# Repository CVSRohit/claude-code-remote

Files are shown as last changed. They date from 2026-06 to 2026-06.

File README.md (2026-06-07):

# Claude Code Remote

A physical remote control for [Claude Code](https://www.claude.com/product/claude-code).
An ESP32 with a 1.3" screen and **four buttons** lets you **launch prompts**,
**approve or deny every tool call with a button**, **scroll Claude's output**, and
**interrupt a run** — from anywhere, while Claude runs on your own PC against your
own files.

```
┌─────────────────────────┐   wss/TLS   ┌──────────────┐   wss (outbound)   ┌────────────────────────────┐
│ ESP32                   │ ──────────▶ │  Fly.io relay │ ◀───────────────── │  runner (Node, your PC)    │
│ ST7789 240x240          │             │  token-paired │                    │   → Claude Agent SDK       │
│ 4 buttons  ▲ ▼ ✓ ✗     │ ◀────────── │   WS hub      │ ─────────────────▶ │   → Claude Code + your fs  │
└─────────────────────────┘             └──────────────┘                    └────────────────────────────┘
        approve / deny / launch / interrupt              status / tool / text / result
```

Claude Code can't run on an ESP32 (it needs Node + a filesystem), so the ESP32 is
a thin client. This mirrors Claude Code's own **Remote Control** model — the
machine that owns the files dials *outbound* to a relay, nothing inbound — except
here the runner uses the **Agent SDK**, whose `canUseTool` callback gives you the
physical **approve/deny** that the official remote control can't do.

Three components, one per folder:

| Folder | Runs on | What it is |
|---|---|---|
| `relay/` | Fly.io (or any host) | A tiny stateless WebSocket hub. Pairs one device to one runner by a shared token and forwards JSON. Holds no API key, no files. |
| `bridge/` | Your PC | The "runner". Dials out to the relay, drives Claude Code via the Agent SDK against your local files. |
| `firmware/` | ESP32 | The handheld remote (PlatformIO). |

## 🛠 Build one yourself

Full parts list, wiring, 3D-printed case, and step-by-step assembly are in
**[docs/BUILD.md](docs/BUILD.md)**. Printable STLs (base, lid, fit-test) and the
parametric source live in **[hardware/case](hardware/case)**.

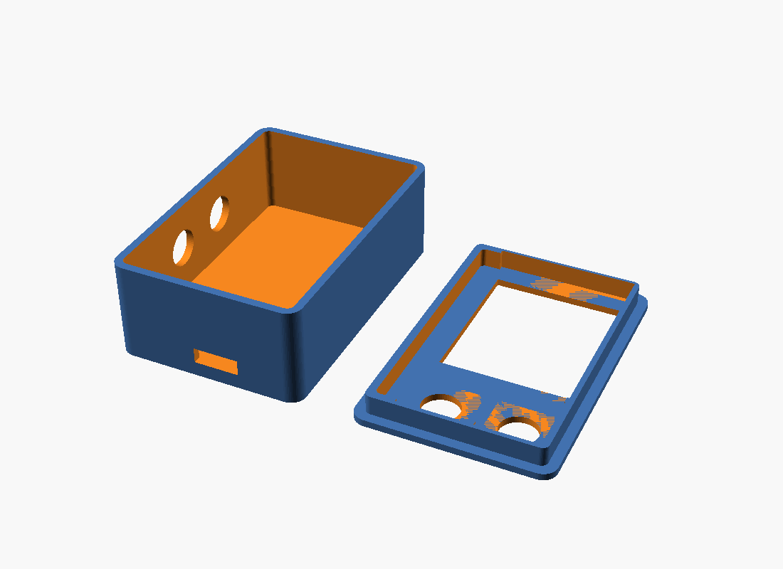
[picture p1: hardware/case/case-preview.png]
case preview


## Two modes (toggle on-device — top menu row, press ✓)

- **ask**  — the SDK `canUseTool` callback *blocks* on each tool call; the screen
  shows the command and waits: **✓ = allow, ✗ = deny**.
- **auto** — `permissionMode: bypassPermissions` runs unattended, but a
  `PreToolUse` hook still streams every tool call to the screen so you *see* every
  action. Hit **✗ while running to interrupt**.

---

## Setup

A shared **token** ties all three pieces together. Generate one:

```bash
node -e "console.log(require('crypto').randomBytes(18).toString('base64url'))"
```

### 1. Relay (Fly.io)

```bash
cd relay
fly apps create your-relay-name
fly secrets set RELAY_TOKEN=<token> --app your-relay-name --stage
fly deploy --app your-relay-name --ha=false   # edit app name in fly.toml first
```

Your relay is now at `wss://your-relay-name.fly.dev/`.

### 2. Runner (your PC)

Requires Node 18+ and Claude Code authenticated on this machine (the Agent SDK
reuses your existing Claude Code auth).

```bash
cd bridge
npm install
cp .env.example .env        # set RELAY_URL=wss://your-relay-name.fly.dev/ and RELAY_TOKEN=<token>
npm start
```

Edit `presets.json` to change the menu and which folder Claude operates in
(`defaultCwd`, or per-preset `cwd`).

### 3. Firmware (ESP32)

```bash
cd firmware
cp include/secrets.h.example include/secrets.h   # set WiFi (2.4GHz), RELAY_HOST, RELAY_TOKEN
pio run -t upload
pio device monitor
```

---

## Wiring (ESP32 devkit → ST7789 240×240)

| ST7789 | ESP32 | | Button | ESP32 |
|---|---|-|---|---|
| VCC | 3V3 | | ▲ UP | GPIO25 → GND |
| GND | GND | | ▼ DOWN | GPIO26 → GND |
| SCL/SCLK | GPIO18 | | ✓ OK (green) | GPIO27 → GND |
| SDA/MOSI | GPIO23 | | ✗ BACK (red) | GPIO33 → GND |
| RES/RST | GPIO4 | | | |
| DC | GPIO2 | | | |
| BLK | GPIO32 | | | |

- **No CS pin** — these 7-pin boards have CS tied active internally; `platformio.ini`
  sets `TFT_CS=-1`. Leave it unconnected.
- **VCC = 3.3V, not 5V** (the panel logic is 3.3V; no onboard regulator).
- **BLK → GPIO32** so firmware controls the backlight: it sleeps after 60s idle
  and wakes on any button or an incoming approval. Prefer always-on? Wire BLK to
  3V3 instead (the screen just won't sleep).
- Buttons are bare tactile switches, one leg to the GPIO and one to GND — internal
  pull-ups, no resistors.
- SPI is set to 27 MHz in `platformio.ini`; drop it (e.g. 10 MHz) if a long/cheap
  jumper run gives a blank screen.

TFT pins live in `platformio.ini` `build_flags`; button pins at the top of
`firmware/src/main.cpp`.

## Controls

| Screen | ▲ UP | ▼ DOWN | ✓ OK | ✗ BACK |
|---|---|---|---|---|
| Menu | prev row | next row | activate row¹ | — |
| Approval | scroll cmd ↑ | scroll cmd ↓ | **ALLOW** | **DENY** |
| Running  | scroll log ↑ | scroll log ↓ | — | **interrupt run** |
| Result | scroll ↑ | scroll ↓ | back to menu | back to menu |

¹ The menu's top row is `Mode: ask/auto` — ✓ toggles the mode; ✓ on any other row
launches that preset.

## Security

The relay is reachable on the public internet, so it's **token-gated**: a client
must present the shared `RELAY_TOKEN` to be paired into a room. Keep it secret —
it (and your WiFi password) live in gitignored files (`bridge/.env`,
`firmware/include/secrets.h`); `.example` templates are committed. In `auto` mode
the runner uses `bypassPermissions`, so treat the token like a key to your shell.

## 3D-printed enclosure

A two-part handheld case (base + lid) is in [`hardware/case`](hardware/case) —
printable STLs plus a parametric OpenSCAD source you can tweak to your exact
boards. **Print `fit-test.stl` first** to check the screen/button fit. See the
[build guide](docs/BUILD.md#3-print-the-case) for print settings and assembly.

## Notes & extensions

- Single device + single runner per token; newest connection of each role wins.
- Output is buffered on-device into a scrollable log; ▲/▼ scroll, the running log
  auto-follows the newest line until you scroll up.
- Interrupt: ✗ while running sends `{type:"interrupt"}`; the runner aborts the run.
- Want free-form prompts without a keyboard? The ESP32 pairs well with an INMP441
  mic — capture audio, send to the runner, transcribe, feed as a prompt.

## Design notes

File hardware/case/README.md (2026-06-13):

# Enclosure — 3D printed case

A custom two-part handheld case for the Claude Code Remote, sized to an ESP32
(52×28, USB-C) with a 1.3" ST7789 bolted on top (~17 mm stack). **~39 × 58 × 21 mm.**

| File | Print | Notes |
|---|---|---|
| `base.stl` | 1× | Tray for the ESP32+screen stack. USB-C cutout on the bottom end; 2 cap holes on the left wall for the scroll buttons. |
| `lid.stl` | 1× | Front plate: screen window + the 2 action-button cap holes below it. Print **face-down**. |
| `claude-code-remote-case.scad` | — | Parametric source — every dimension is at the top. |

preview

## Layout

- **Screen** centered up top behind the lid window (1.4 mm bezel).
- **Action buttons (✓ ✗)** — two 7.6 mm cap holes on the lid, below the screen.
- **Scroll buttons (▲ ▼)** — two 7.6 mm cap holes on the **left wall**; the
  12×12×3 mm switches stand on edge in the left channel, caps facing out.
- No screws — **base and lid glue/tape together**; the side switches glue into
  the channel.

## Print settings

PLA or PETG · 0.2 mm layers · 4 perimeters (walls are 1.6 mm) · 20% infill ·
**no supports** (print the lid face-down).

## Customizing

Open `claude-code-remote-case.scad`, edit the `CONFIG` block (board size, stack
height, screen window, button positions, channel width, wall thickness), then:

```bash
openscad -o base.stl -D pn=1 claude-code-remote-case.scad
openscad -o lid.stl  -D pn=2 claude-code-remote-case.scad
```

See [`../../docs/BUILD.md`](../../docs/BUILD.md) for the full build.

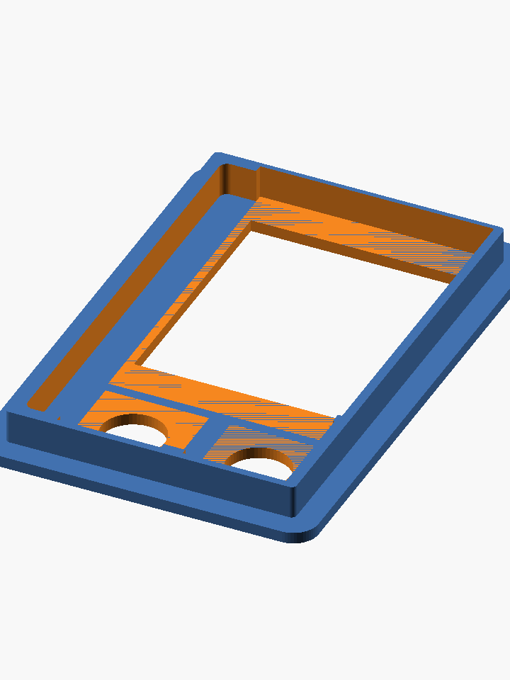
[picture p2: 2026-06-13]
hardware/case/lid-front.png

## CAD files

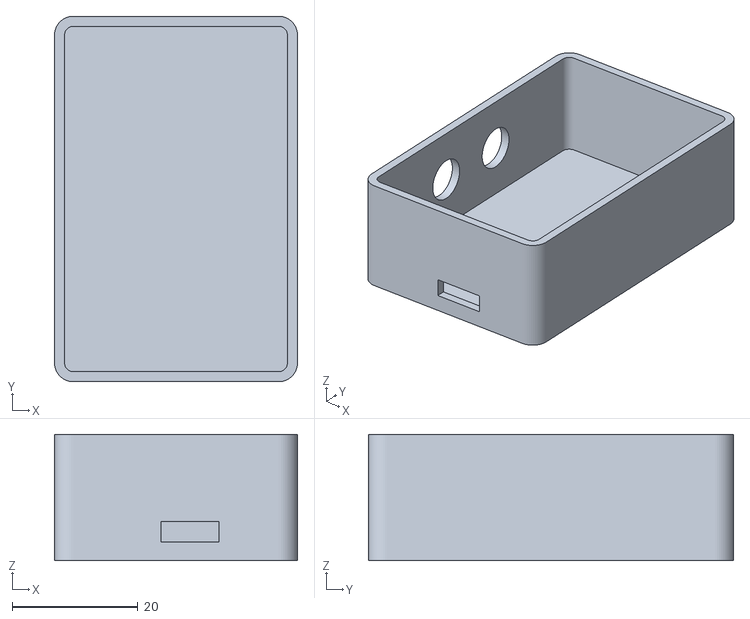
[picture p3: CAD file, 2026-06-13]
hardware/case/base.stl
38.7 x 58.2 x 20.1

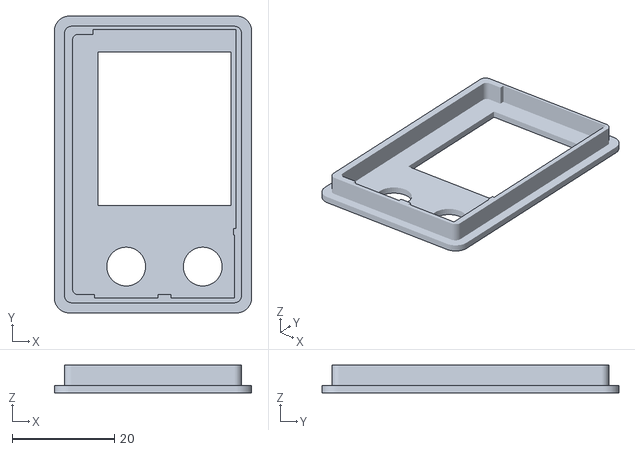
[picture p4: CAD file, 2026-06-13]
hardware/case/lid.stl
38.7 x 58.2 x 5.40

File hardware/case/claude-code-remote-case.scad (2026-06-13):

/* ============================================================
   Claude Code Remote — custom handheld case (v3)

   Layout:
     - ESP32 (52x28, USB-C) + ST7789 stacked on the RIGHT side of the case.
     - A LEFT CHANNEL runs alongside the boards; the two SCROLL buttons (▲ ▼)
       stand vertically in it, caps facing OUT the left wall (perpendicular to
       the boards), bodies wedged against the boards' left edges.
     - Screen window at the TOP (over the boards); two ACTION buttons (✓ ✗)
       on the face just below the screen.
     - 2 screws in the left channel (top + bottom), clear of the side buttons.

   Render:
     openscad -o base.stl -D pn=1 claude-code-remote-case.scad
     openscad -o lid.stl  -D pn=2 claude-code-remote-case.scad
   ============================================================ */

part = "both";
pn = -1;  // CLI: 0 both, 1 base, 2 lid

/* ---------------- CONFIG (measure & adjust) ---------------- */
// ESP32
esp_l   = 52;
esp_w   = 28;
esp_h   = 13;     // ESP32 height incl. soldered pins
stack_h = 17;     // ESP32 + ST bolted together (measured)
usb_w   = 9.2;
usb_h   = 3.2;
usb_cz  = 3.0;    // USB-C centre height above floor — CONFIRM

// Screen (ST7789)
scr_pcb_w = 28;
scr_pcb_l = 39;
scr_pcb_t = 1.8;
scr_win_w = 26;   // +1mm wider
scr_win_h = 30;
scr_cy    = 7;    // screen centre toward the TOP
scr_gap   = 6;    // gap ESP32 top -> screen — CONFIRM

// Buttons: 12x12x5 DIP tactile, 7mm round cap
btn       = 12.4; // square body footprint
btn_hole  = 7.6;  // round cap hole
btn_depth = 3;    // switch body depth into the channel
fbtn_y    = -20;  // action buttons centre line, clear of the ST PCB above
fbtn_dx   = 7.5;  // their left/right spacing
sbtn_y1   = 7;    // scroll ▲ (left channel, toward top)
sbtn_y2   = -7;   // scroll ▼ (left channel, toward bottom)

// Case
channel_w  = 6;     // left channel width for the side buttons (3mm switch + room)
right_clear = 1.5;  // clearance on the board (right) side
wall   = 1.6;   // base wall thickness (4 perimeters @ 0.4 nozzle)
gap    = 0.4;
fillet = 3;
lip_h  = 4;
lip_wall = 1.6;
screw_pilot = 1.7;
screw_clear = 2.4;
screw_head  = 4.2;
post_d      = 5.0;
post_inset  = 3.0;

$fn = 56;

/* ---------------- DERIVED ---------------- */
inner_w = esp_w + right_clear + channel_w;          // boards right, channel left
inner_l = esp_l + 3;
inner_d = stack_h + 1.5;                             // fit the bolted ESP32+ST stack
board_cx = inner_w / 2 - right_clear - esp_w / 2;   // board centre, shifted right
sbtn_z  = wall + inner_d / 2;                        // side button centre depth
out_w = inner_w + 2 * wall;
out_l = inner_l + 2 * wall;
base_d = inner_d + wall;
lid_t  = 1.4;   // thin face so 3mm button caps poke through (matches screen bezel)

/* ---------------- HELPERS ---------------- */
module rbox(w, l, h, r) {
  hull() for (x = [-1, 1], y = [-1, 1])
    translate([x * (w / 2 - r), y * (l / 2 - r), 0]) cylinder(h = h, r = r);
}
module post_xy() {  // 2 posts in the LEFT channel (top + bottom)
  for (y = [-1, 1])
    translate([-(inner_w / 2 - post_inset), y * (inner_l / 2 - post_inset), 0]) children();
}

/* ---------------- BASE ---------------- */
module base() {
  difference() {
    rbox(out_w, out_l, base_d, fillet);
    translate([0, 0, wall]) rbox(inner_w, inner_l, base_d, max(0.6, fillet - wall));
    // USB-C on bottom end wall, aligned to the board (shifted right)
    translate([board_cx, -out_l / 2, wall + usb_cz]) cube([usb_w, 3 * wall, usb_h], center = true);
    // scroll buttons: round cap holes through the LEFT (-x) wall only
    for (yy = [sbtn_y1, sbtn_y2])
      translate([-out_w / 2 - 1, yy, sbtn_z]) rotate([0, 90, 0]) cylinder(h = wall + 3, d = btn_hole);
  }
  // (side-button switches glue into the channel; base+lid glue/tape together)
}

/* ---------------- LID ---------------- */
module lid() {
  difference() {
    union() {
      rbox(out_w, out_l, lid_t, fillet);
      translate([0, 0, lid_t - 0.5]) difference() {
        rbox(inner_w - 2 * gap, inner_l - 2 * gap, lip_h + 0.5, max(0.6, fillet - wall));
        translate([0, 0, -1]) rbox(inner_w - 2 * gap - 2 * lip_wall, inner_l - 2 * gap - 2 * lip_wall, lip_h + 2.5, 1);
      }
    }
    // screen PCB recess (bezel ~1.4mm), shifted right over the boards
    translate([board_cx - scr_pcb_w / 2, scr_cy - scr_pcb_l / 2, 1.4])
      cube([scr_pcb_w, scr_pcb_l, lid_t + lip_h + 2]);
    // screen window
    translate([board_cx, scr_cy, -1])
      linear_extrude(lid_t + lip_h + 2) square([scr_win_w, scr_win_h], center = true);
    // action buttons below the screen (cap holes + 12x12 body wells)
    for (x = [-1, 1]) {
      translate([board_cx + x * fbtn_dx, fbtn_y, -1]) cylinder(h = lid_t + 2, d = btn_hole);
      translate([board_cx + x * fbtn_dx, fbtn_y, lid_t]) linear_extrude(lip_h + 1) square([btn, btn], center = true);
    }
  }
}

/* ---------------- RENDER ---------------- */
sel = pn == 0 ? "both" : pn == 1 ? "base" : pn == 2 ? "lid" : part;
if (sel == "base") base();
else if (sel == "lid") lid();
else { base(); translate([out_w + 10, 0, 0]) lid(); }

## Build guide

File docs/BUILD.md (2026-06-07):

# Build your own Claude Code Remote

This guide takes you from parts to a working handheld remote. For how the system
works end-to-end, see the [main README](../README.md).

Rough time: **1–2 hours** (plus print time). Skill level: beginner-friendly
soldering (4 buttons) + flashing a dev board.

---

## 1. Bill of materials

| # | Part | Qty | ~Cost | Notes |
|---|---|-----|---|---|
| 1 | **ESP32 dev board** (DevKitC / WROOM-32, 38-pin) | 1 | $5–8 | Any ESP32 with a USB-serial chip (CP2102/CH340). |
| 2 | **1.3" ST7789 IPS display**, 240×240, SPI, **7-pin (no CS)** | 1 | $5–7 | Pin order `GND VCC SCL SDA RES DC BLK`. 3.3V board. |
| 3 | **6×6 mm tactile push buttons** | 4 | ~$1 | Through-hole, ~5 mm plunger. |
| 4 | **Jumper wires** (female–female) | ~12 | ~$2 | To connect display + buttons to the header pins. |
| 5 | **M2 × 6 mm self-tapping screws** | 2 | ~$1 | Hold the lid to the base. |
| 6 | **USB data cable** | 1 | — | Match your board (micro-USB or USB-C). **Data**, not charge-only. |
| 7 | **3D-printed case** (base + lid) | 1 set | filament | See [`hardware/case`](../hardware/case). |
| 8 | Foam pad / double-sided tape | a little | — | Optional: pad the ESP32 in the tray, hold the screen. |

You also need a **2.4 GHz WiFi** network (ESP32 has no 5 GHz) and a PC that runs
Claude Code, plus a [Fly.io](https://fly.io) account (free tier is fine) for the
relay.

### Tools
- Soldering iron + solder (to attach wires to the 4 buttons)
- 3D printer (or a print service)
- Small Phillips screwdriver
- A computer with [PlatformIO](https://platformio.org) and [Node 18+](https://nodejs.org)

---

## 2. Wiring

All display power is **3.3V** (not 5V). All grounds are common.

### Display (ST7789) → ESP32

| ST7789 | ESP32 |
|---|---|
| VCC | 3V3 |
| GND | GND |
| SCL | GPIO18 |
| SDA | GPIO23 |
| RES | GPIO4 |
| DC  | GPIO2 |
| BLK | GPIO32 |

> No CS pin — the firmware sets `TFT_CS=-1`. Leave it unconnected.
> BLK is on GPIO32 (not 3V3) so the firmware can sleep the backlight after 60s
> idle and wake on a button/approval. Wire BLK to 3V3 instead if you want it
> always on.

### Buttons → ESP32

Each button: one leg to its GPIO, the other leg to **GND** (all four GND legs can
share one ground wire). Internal pull-ups are enabled, so no resistors.

| Button | ESP32 |
|---|---|
| ▲ UP | GPIO25 |
| ▼ DOWN | GPIO26 |
| ✓ OK (green) | GPIO27 |
| ✗ BACK (red) | GPIO33 |

---

## 3. Print the case

In [`hardware/case`](../hardware/case):

1. **Print `fit-test.stl` first** and check your screen + buttons drop into it.
   Adjust the `CONFIG` block in the `.scad` and re-render if anything is off.
2. Print `base.stl` and `lid.stl` (print the lid **front-face-down**).

Print settings: PLA/PETG, 0.2 mm layers, 3 walls, 20% infill, no supports.

case preview

---

## 4. Assemble

1. **Buttons:** solder a wire to each button (signal + ground). Press the four
   buttons into the wells on the inside of the lid (▲▼ left column, ✓✗ right).
2. **Screen:** seat the display into the recess behind the lid window, active area
   facing out. Hold it with a dab of hot glue or tape on the PCB edges.
3. **Wire it up** per section 2 — display and buttons to the ESP32 header.
4. **ESP32:** place it in the base with the USB port lined up to the cutout. Pad
   with foam/tape so it doesn't rattle.
5. Close the lid onto the base and fasten the **2 M2 screws** at the bottom.

---

## 5. Flash the firmware

```bash
cd firmware
cp include/secrets.h.example include/secrets.h
# edit secrets.h: WIFI_SSID/PASS (2.4GHz), RELAY_HOST, RELAY_TOKEN
pio run -t upload
pio device monitor          # watch it boot, join WiFi, connect to the relay
```

You generate `RELAY_TOKEN` and deploy the relay in the next step — come back and
fill it in.

---

## 6. Software: relay + runner

Do this once. Full detail is in the [README](../README.md#setup); the short version:

```bash
# pick a shared secret used by the relay, runner, and firmware
node -e "console.log(require('crypto').randomBytes(18).toString('base64url'))"

# relay (Fly.io) — edit the app name in relay/fly.toml first
cd relay
fly apps create your-relay-name
fly secrets set RELAY_TOKEN=<token> --app your-relay-name --stage
fly deploy --app your-relay-name --ha=false

# runner (your PC, where Claude Code is logged in)
cd ../bridge
npm install
cp .env.example .env        # RELAY_URL=wss://your-relay-name.fly.dev/  +  RELAY_TOKEN=<token>
npm start
```

Put the same `RELAY_HOST` (`your-relay-name.fly.dev`) and `RELAY_TOKEN` into
`firmware/include/secrets.h` and re-flash.

---

## 7. First run

1. Runner terminal shows `Paired with relay (device online: true)`.
2. The device screen shows the menu: `MODE: ask` + your presets.
3. Highlight a preset with ▲/▼, press ✓ to launch.
4. In **ask** mode each tool call shows on screen — press ✓ to allow, ✗ to deny.
5. It finishes on a green **DONE** screen with the run cost.

Point the runner at any local folder (or a cloned repo) via `defaultCwd` / per-preset
`cwd` in `bridge/presets.json`.

---

## 8. Troubleshooting

| Symptom | Fix |
|---|-----|
| **Screen lit but blank** | A loose/wrong data wire (DC, RES, SDA, SCL) — re-seat them. If on long jumpers, lower `SPI_FREQUENCY` in `platformio.ini` (try 10 MHz). |
| **Screen totally dark** | No backlight — check BLK→3V3, VCC→3V3, common GND. |
| **Screen garbled / wrong colors** | SPI integrity (shorten/reseat wires, lower SPI freq) or driver flags. |
| **Won't connect to WiFi** | Must be **2.4 GHz**; check SSID/pass in `secrets.h`. |
| **`Waiting for runner`** | The runner isn't connected — start it (`npm start`) and check `RELAY_TOKEN` matches in all three places. |
| **`auth failed` on screen** | Token mismatch between firmware, runner `.env`, and the Fly secret. |
| **Upload "chip stopped responding"** | Hold the **BOOT** button during upload, or unplug/replug and retry. |
| **Buttons do the wrong thing** | Check each button's GPIO matches section 2. |

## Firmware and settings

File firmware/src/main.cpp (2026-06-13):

/**
 * Claude Code remote — ESP32 firmware (4-button edition).
 *
 * Hardware: ESP32 + 1.3" ST7789 240x240 IPS LCD + 4 tactile buttons.
 * Talks JSON over WebSocket to the PC bridge (see ../bridge).
 *
 * Buttons (all active-low to GND, internal pull-ups):
 *   UP (▲)  DOWN (▼)  OK (✓, green)  BACK (✗, red)
 *
 * Each button keeps ONE meaning everywhere:
 *   ▲ / ▼  always move the selection or scroll text
 *   ✓      always the affirmative  (launch / allow / continue)
 *   ✗      always the negative     (deny / back / interrupt)
 *
 * Per-screen behaviour:
 *   MENU     : ▲/▼ move, ✓ activate row (row 0 = toggle ask/auto, rest = launch)
 *   RUNNING  : ▲/▼ scroll log, ✗ interrupt the run
 *   APPROVAL : ▲/▼ scroll command, ✓ ALLOW, ✗ DENY
 *   RESULT   : ▲/▼ scroll output, ✓ or ✗ back to menu
 *
 * See README.md for wiring.
 */

#include <Arduino.h>
#include <WiFi.h>
#include <WebSocketsClient.h>
#include <ArduinoJson.h>
#include <TFT_eSPI.h>

// ---------- USER CONFIG ----------
// Real values live in include/secrets.h (gitignored). The fallbacks below let
// the project compile without it. RELAY_TOKEN must match the runner + Fly secret.
#if defined(__has_include)
#  if __has_include("secrets.h")
#    include "secrets.h"
#  endif
#endif
#ifndef WIFI_SSID
#  define WIFI_SSID "YOUR_WIFI"
#endif
#ifndef WIFI_PASS
#  define WIFI_PASS "YOUR_PASSWORD"
#endif
#ifndef RELAY_HOST
#  define RELAY_HOST "cc-remote-relay-rohit.fly.dev"
#endif
#ifndef RELAY_PORT
#  define RELAY_PORT 443
#endif
#ifndef RELAY_TOKEN
#  define RELAY_TOKEN "PASTE_TOKEN_HERE"
#endif

// ---------- PINS (buttons, active-low) ----------
static const int PIN_UP = 25;   // ▲
static const int PIN_DOWN = 26;  // ▼
static const int PIN_OK = 27;    // ✓ green
static const int PIN_BACK = 33;  // ✗ red
static const int PIN_BL = 32;    // backlight enable (move display BLK here from 3V3)
// TFT pins are set in platformio.ini build flags.

// ---------- GLOBALS ----------
TFT_eSPI tft = TFT_eSPI();
WebSocketsClient ws;

enum UiState { ST_BOOT, ST_SESSIONS, ST_MENU, ST_MONITOR, ST_RUNNING, ST_APPROVAL, ST_RESULT };
UiState state = ST_BOOT;

static const int MAX_PRESETS = 10;
String presetLabels[MAX_PRESETS];
int presetCount = 0;
int selection = 0; // 0 = mode row, 1..presetCount = presets

static const int MAX_SESSIONS = 8;
String sessionNames[MAX_SESSIONS];
String sessionIds[MAX_SESSIONS];
int sessionCount = 0;
int sessionSel = 0;

String currentMode = "ask";
String statusText = "Connecting…";
String toolName = "";
String toolSummary = "";
String pendingToolId = "";
String logBuf = "";   // accumulated tool calls + prose during a run
String resultText = "";
bool resultOk = false;
float resultCost = 0;

int scroll = 0;          // line offset for scrollable views
bool followBottom = true; // auto-stick RUNNING log to the newest line
bool dirty = true;        // redraw flag
bool wsUp = false;        // websocket connected (diagnostics)
bool screenAsleep = false;       // backlight off after idle
uint32_t lastActivity = 0;       // last button / message time
static const uint32_t SLEEP_MS = 60000; // idle timeout before backlight off
void wake();        // forward decls (used in handleMessage, defined near setup)
void sleepScreen();

// ---------- COLORS ----------
#define COL_BG TFT_BLACK
#define COL_ACCENT 0x05D4 // teal
#define COL_DIM 0x7BEF
#define COL_OK 0x07E0
#define COL_BAD 0xF800
#define COL_WARN 0xFD20

// ---------- LAYOUT ----------
#define BODY_Y 30
#define LINE_H 12
static const int CHARS_PER_LINE = 37; // ~224px / 6px (font 1)

// Debounced active-low edge detector.
struct Button {
  int pin;
  bool last = HIGH;
  uint32_t tEdge = 0;
  Button(int p) : pin(p) {}
  bool pressed() {
    bool now = digitalRead(pin);
    if (now != last && (millis() - tEdge) > 40) {
      tEdge = millis();
      last = now;
      if (now == LOW) return true;
    }
    last = now;
    return false;
  }
};
Button btnUp{PIN_UP}, btnDown{PIN_DOWN}, btnOk{PIN_OK}, btnBack{PIN_BACK};

// ---------- TEXT WRAP / SCROLL ----------
static const int MAX_LINES = 90;
String wrapped[MAX_LINES];
int lineCount = 0;

// Word-wrap `s` into the `wrapped` array (honours embedded '\n').
void buildLines(const String &s, int perLine) {
  lineCount = 0;
  int start = 0, lastSpace = -1;
  int len = s.length();
  for (int i = 0; i <= len && lineCount < MAX_LINES; i++) {
    char c = (i < len) ? s[i] : '\n';
    if (c == '\n') {
      wrapped[lineCount++] = s.substring(start, i);
      start = i + 1;
      lastSpace = -1;
      continue;
    }
    if (c == ' ') lastSpace = i;
    if (i - start >= perLine) {
      int brk = (lastSpace > start) ? lastSpace : i;
      wrapped[lineCount++] = s.substring(start, brk);
      start = (lastSpace > start) ? brk + 1 : brk;
      lastSpace = -1;
    }
  }
}

// Draw a scrollable block; returns true if more lines exist than fit.
bool drawBody(const String &content, uint16_t color, int yStart, int visLines) {
  buildLines(content, CHARS_PER_LINE);
  int maxScroll = max(0, lineCount - visLines);
  if (followBottom) scroll = maxScroll;
  scroll = constrain(scroll, 0, maxScroll);

  tft.setTextColor(color, COL_BG);
  tft.setTextDatum(TL_DATUM);
  for (int r = 0; r < visLines; r++) {
    int idx = scroll + r;
    if (idx >= lineCount) break;
    tft.drawString(wrapped[idx], 8, yStart + r * LINE_H, 1);
  }
  // Scrollbar thumb on the right edge.
  if (lineCount > visLines) {
    int trackY = yStart, trackH = visLines * LINE_H;
    int thumbH = max(8, trackH * visLines / lineCount);
    int thumbY = trackY + (trackH - thumbH) * scroll / maxScroll;
    tft.fillRect(236, trackY, 3, trackH, COL_BG);
    tft.fillRect(236, thumbY, 3, thumbH, COL_DIM);
    return true;
  }
  return false;
}

void scrollBy(int d) {
  followBottom = false;
  scroll += d;
  if (scroll < 0) scroll = 0;
  dirty = true;
}

// ---------- DRAW ----------
void header(const char *title, uint16_t col) {
  tft.fillRect(0, 0, 240, 26, col);
  tft.setTextColor(TFT_BLACK, col);
  tft.setTextDatum(ML_DATUM);
  tft.drawString(title, 6, 13, 2);
}

void footer(const char *txt) {
  tft.setTextColor(COL_DIM, COL_BG);
  tft.setTextDatum(MC_DATUM);
  tft.drawString(txt, 120, 230, 1);
}

void draw() {
  tft.fillScreen(COL_BG);
  switch (state) {
    case ST_BOOT:
      header("Claude Remote", COL_ACCENT);
      tft.setTextColor(COL_DIM, COL_BG);
      tft.setTextDatum(MC_DATUM);
      tft.drawString(statusText, 120, 130, 2);
      break;

    case ST_SESSIONS: {
      header("SESSIONS", COL_ACCENT);
      if (sessionCount == 0) {
        tft.setTextColor(COL_DIM, COL_BG);
        tft.setTextDatum(MC_DATUM);
        tft.drawString("No sessions online", 120, 115, 2);
        tft.drawString("start the runner on your PC", 120, 145, 1);
      } else {
        for (int i = 0; i < sessionCount && i < 9; i++) {
          int y = 34 + i * 20;
          bool sel = (i == sessionSel);
          if (sel) tft.fillRect(0, y - 2, 240, 19, COL_ACCENT);
          tft.setTextColor(sel ? TFT_BLACK : TFT_WHITE, sel ? COL_ACCENT : COL_BG);
          tft.setTextDatum(ML_DATUM);
          tft.drawString(sessionNames[i], 8, y + 7, 2);
        }
      }
      footer("UP/DN move   OK = control");
      break;
    }

    case ST_MENU: {
      String h = "MODE: " + currentMode;
      header(h.c_str(), COL_ACCENT);
      int rows = presetCount + 1; // row 0 is the mode toggle
      for (int i = 0; i < rows && i < 9; i++) {
        int y = 34 + i * 20;
        bool sel = (i == selection);
        if (sel) tft.fillRect(0, y - 2, 240, 19, COL_ACCENT);
        tft.setTextColor(sel ? TFT_BLACK : TFT_WHITE, sel ? COL_ACCENT : COL_BG);
        tft.setTextDatum(ML_DATUM);
        String label = (i == 0) ? ("Mode: " + currentMode + "  (toggle)")
                                : presetLabels[i - 1];
        tft.drawString(label, 8, y + 7, 2);
      }
      footer("UP/DN move   OK = select");
      break;
    }

    case ST_RUNNING: {
      header("RUNNING", COL_WARN);
      tft.setTextColor(COL_ACCENT, COL_BG);
      tft.setTextDatum(TL_DATUM);
      tft.drawString(statusText.substring(0, CHARS_PER_LINE), 8, BODY_Y, 1);
      drawBody(logBuf, TFT_WHITE, BODY_Y + 16, 14);
      footer("UP/DN scroll   BACK = interrupt");
      break;
    }

    case ST_MONITOR: {
      header("MONITOR", COL_ACCENT);
      tft.setTextColor(COL_DIM, COL_BG);
      tft.setTextDatum(TL_DATUM);
      tft.drawString(statusText.substring(0, CHARS_PER_LINE), 8, BODY_Y, 1);
      drawBody(logBuf, TFT_WHITE, BODY_Y + 14, 14);
      footer("UP/DN scroll   BACK = sessions");
      break;
    }

    case ST_APPROVAL:
      header("APPROVE?", COL_WARN);
      tft.setTextColor(COL_ACCENT, COL_BG);
      tft.setTextDatum(TL_DATUM);
      tft.drawString(toolName, 8, BODY_Y, 4);
      drawBody(toolSummary, TFT_WHITE, BODY_Y + 30, 11);
      tft.fillRoundRect(8, 196, 108, 30, 6, COL_OK);
      tft.fillRoundRect(124, 196, 108, 30, 6, COL_BAD);
      tft.setTextColor(TFT_BLACK);
      tft.setTextDatum(MC_DATUM);
      tft.drawString("OK = ALLOW", 62, 211, 2);
      tft.drawString("BACK = DENY", 178, 211, 2);
      break;

    case ST_RESULT: {
      header(resultOk ? "DONE" : "FAILED", resultOk ? COL_OK : COL_BAD);
      drawBody(resultText, TFT_WHITE, BODY_Y, 15);
      char buf[48];
      snprintf(buf, sizeof(buf), "$%.4f   OK/BACK = menu", resultCost);
      footer(buf);
      break;
    }
  }
}

// ---------- NETWORK ----------
void sendJson(const JsonDocument &doc) {
  String out;
  serializeJson(doc, out);
  ws.sendTXT(out);
}

// Append a line to the run log (keep it bounded so RAM stays sane).
void logLine(const String &s) {
  logBuf += s;
  logBuf += "\n";
  if (logBuf.length() > 2000) logBuf.remove(0, logBuf.length() - 2000);
  followBottom = true;
}

void handleMessage(const String &payload) {
  JsonDocument doc;
  if (deserializeJson(doc, payload)) return;
  String type = doc["type"] | "";

  if (type == "relay") {
    String ev = String((const char *)(doc["event"] | ""));
    if (ev == "session-offline") {
      statusText = "Session offline";
      state = ST_SESSIONS;
      JsonDocument d; d["type"] = "list"; sendJson(d); // refresh the picker
    } else if (ev == "error") {
      statusText = String((const char *)(doc["text"] | "relay error"));
    }
    dirty = true;
    return;
  }

  if (type == "sessions") {
    sessionCount = 0;
    for (JsonObject it : doc["items"].as<JsonArray>()) {
      if (sessionCount < MAX_SESSIONS) {
        sessionIds[sessionCount] = String((const char *)(it["id"] | ""));
        sessionNames[sessionCount] = String((const char *)(it["name"] | "session"));
        sessionCount++;
      }
    }
    if (sessionSel >= sessionCount) sessionSel = 0;
    if (state == ST_BOOT || state == ST_SESSIONS) state = ST_SESSIONS;
    dirty = true;
    return;
  }

  if (type == "monitor") {
    statusText = String((const char *)(doc["name"] | "monitor"));
    logBuf = "";
    scroll = 0;
    followBottom = true;
    state = ST_MONITOR;
    wake();
    return;
  }

  if (type == "presets") {
    presetCount = 0;
    for (JsonObject it : doc["items"].as<JsonArray>()) {
      if (presetCount < MAX_PRESETS) presetLabels[presetCount++] = String((const char *)it["label"]);
    }
    currentMode = String((const char *)(doc["mode"] | "ask"));
    selection = 0;
    state = ST_MENU;
  } else if (type == "status") {
    statusText = String((const char *)(doc["text"] | ""));
    if (doc["mode"].is<const char *>()) currentMode = String((const char *)doc["mode"]);
    String st = String((const char *)(doc["state"] | ""));
    if (st == "idle" && state != ST_RESULT) state = ST_MENU;
    else if ((st == "thinking" || st == "running" || st == "busy") && state != ST_APPROVAL) {
      if (state != ST_RUNNING) { logBuf = ""; followBottom = true; }
      state = ST_RUNNING;
    }
  } else if (type == "tool") {
    toolName = String((const char *)(doc["name"] | ""));
    toolSummary = String((const char *)(doc["summary"] | ""));
    if (doc["needsApproval"] | false) {
      pendingToolId = String((const char *)(doc["id"] | ""));
      scroll = 0;
      followBottom = false;
      state = ST_APPROVAL;
    } else {
      logLine("> " + toolName + ": " + toolSummary); // auto mode: just record it
      state = ST_RUNNING;
    }
  } else if (type == "text") {
    logLine(String((const char *)(doc["text"] | "")));
  } else if (type == "result") {
    resultOk = doc["ok"] | false;
    resultCost = doc["cost"] | 0.0;
    resultText = String((const char *)(doc["text"] | ""));
    toolName = "";
    toolSummary = "";
    scroll = 0;
    followBottom = false;
    state = ST_RESULT;
  }
  wake(); // any runner message lights the screen + resets the idle timer
}

void wsEvent(WStype_t type, uint8_t *payload, size_t len) {
  switch (type) {
    case WStype_CONNECTED: {
      wsUp = true;
      Serial.println("[ws] CONNECTED -> sending hello");
      statusText = "Pairing…";
      JsonDocument h;
      h["type"] = "hello";
      h["role"] = "device";
      h["token"] = RELAY_TOKEN;
      sendJson(h);
      dirty = true;
      break;
    }
    case WStype_DISCONNECTED:
      wsUp = false;
      Serial.println("[ws] DISCONNECTED");
      statusText = "Reconnecting…";
      state = ST_BOOT;
      dirty = true;
      break;
    case WStype_ERROR:
      Serial.printf("[ws] ERROR len=%u: %.*s\n", (unsigned)len, (int)len, (char *)payload);
      break;
    case WStype_TEXT:
      handleMessage(String((char *)payload, len));
      break;
    default:
      break;
  }
}

// ---------- ACTIONS ----------
void selectSession(int idx) {
  JsonDocument d;
  d["type"] = "select";
  d["id"] = sessionIds[idx];
  sendJson(d);
  statusText = "Loading session…";
  state = ST_BOOT;
  dirty = true;
}

void launchPreset(int idx) {
  JsonDocument d;
  d["type"] = "launch";
  d["id"] = idx;
  sendJson(d);
}

void sendApproval(bool allow) {
  JsonDocument d;
  d["type"] = "approve";
  d["id"] = pendingToolId;
  d["allow"] = allow;
  sendJson(d);
  pendingToolId = "";
  followBottom = true;
  state = ST_RUNNING;
  dirty = true;
}

void toggleMode() {
  currentMode = (currentMode == "ask") ? "auto" : "ask";
  JsonDocument d;
  d["type"] = "mode";
  d["mode"] = currentMode;
  sendJson(d);
  dirty = true;
}

void sendInterrupt() {
  JsonDocument d;
  d["type"] = "interrupt";
  sendJson(d);
  statusText = "Interrupting…";
  dirty = true;
}

// ---------- SLEEP ----------
void wake() {
  lastActivity = millis();
  if (screenAsleep) {
    screenAsleep = false;
    digitalWrite(PIN_BL, HIGH); // backlight on; GRAM content is still there
  }
  dirty = true;
}
void sleepScreen() {
  screenAsleep = true;
  digitalWrite(PIN_BL, LOW); // backlight off only; panel keeps its content
}

// ---------- SETUP / LOOP ----------
void setup() {
  Serial.begin(115200);
  pinMode(PIN_UP, INPUT_PULLUP);
  pinMode(PIN_DOWN, INPUT_PULLUP);
  pinMode(PIN_OK, INPUT_PULLUP);
  pinMode(PIN_BACK, INPUT_PULLUP);
  pinMode(PIN_BL, OUTPUT);
  digitalWrite(PIN_BL, HIGH); // backlight on
  lastActivity = millis();

  Serial.println("[tft] init");
  tft.init();
  tft.setRotation(0);
  // --- temporary display self-test: R, G, B, then HELLO ---
  tft.fillScreen(TFT_RED);
  delay(500);
  tft.fillScreen(TFT_GREEN);
  delay(500);
  tft.fillScreen(TFT_BLUE);
  delay(500);
  tft.fillScreen(TFT_BLACK);
  tft.setTextColor(TFT_WHITE, TFT_BLACK);
  tft.setTextDatum(MC_DATUM);
  tft.drawString("HELLO", 120, 120, 4);
  delay(800);
  Serial.println("[tft] selftest done");
  draw();

  WiFi.begin(WIFI_SSID, WIFI_PASS);
  while (WiFi.status() != WL_CONNECTED) {
    delay(300);
    Serial.print(".");
  }
  Serial.printf("\nWiFi OK: %s\n", WiFi.localIP().toString().c_str());

  ws.beginSSL(RELAY_HOST, RELAY_PORT, "/");
  ws.onEvent(wsEvent);
  ws.setReconnectInterval(3000);
}

void loop() {
  ws.loop();

  bool up = btnUp.pressed();
  bool down = btnDown.pressed();
  bool ok = btnOk.pressed();
  bool back = btnBack.pressed();

  bool anyBtn = up || down || ok || back;
  if (anyBtn) {
    Serial.printf("[btn] %s%s%s%s (state=%d)\n",
                  up ? "UP " : "", down ? "DOWN " : "",
                  ok ? "OK " : "", back ? "BACK " : "", (int)state);
    lastActivity = millis();
  }

  // While asleep, the first press only wakes the screen — it doesn't act.
  if (screenAsleep) {
    if (anyBtn) wake();
    up = down = ok = back = false;
  }

  switch (state) {
    case ST_SESSIONS:
      if (sessionCount > 0 && (up || down)) {
        sessionSel = (sessionSel + (down ? 1 : -1) + sessionCount) % sessionCount;
        dirty = true;
      }
      if (ok && sessionCount > 0) selectSession(sessionSel);
      break;
    case ST_MENU: {
      int rows = presetCount + 1;
      if (rows > 0 && (up || down)) {
        selection = (selection + (down ? 1 : -1) + rows) % rows;
        dirty = true;
      }
      if (ok) {
        if (selection == 0) toggleMode();
        else launchPreset(selection - 1);
      }
      if (back) { // back to the session picker
        state = ST_SESSIONS;
        JsonDocument d; d["type"] = "list"; sendJson(d);
        dirty = true;
      }
      break;
    }
    case ST_RUNNING:
      if (up) scrollBy(-3);
      if (down) scrollBy(3);
      if (back) sendInterrupt();
      break;
    case ST_MONITOR:
      if (up) scrollBy(-3);
      if (down) scrollBy(3);
      if (back) {
        JsonDocument d; d["type"] = "interrupt"; sendJson(d); // stop tailing
        state = ST_SESSIONS;
        JsonDocument l; l["type"] = "list"; sendJson(l);
        dirty = true;
      }
      break;
    case ST_APPROVAL:
      if (up) scrollBy(-3);
      if (down) scrollBy(3);
      if (ok) sendApproval(true);
      if (back) sendApproval(false);
      break;
    case ST_RESULT:
      if (up) scrollBy(-3);
      if (down) scrollBy(3);
      if (ok || back) { state = ST_MENU; selection = 0; dirty = true; }
      break;
    default:
      break;
  }

  if (!screenAsleep && millis() - lastActivity > SLEEP_MS) sleepScreen();

  static uint32_t lastHb = 0;
  if (millis() - lastHb > 5000) {
    lastHb = millis();
    Serial.printf("[hb] wifi=%d wsUp=%d heap=%u state=%d st=%s\n",
                  WiFi.status() == WL_CONNECTED, wsUp, (unsigned)ESP.getFreeHeap(),
                  (int)state, statusText.c_str());
  }

  if (dirty && !screenAsleep) {
    dirty = false;
    draw();
  }
  delay(5);
}

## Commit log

2026-06-06 Initial commit: Claude Code hardware remote
    ESP32 + ST7789 + 4 buttons that drives Claude Code on your PC via a
    Fly.io token-paired WebSocket relay and the Claude Agent SDK. Physical
    approve/deny, scrollable output, interrupt. Secrets gitignored.
2026-06-06 Add build guide, BOM, 3D-printed case (STLs), and LICENSE
    - docs/BUILD.md: full DIY guide — parts list, wiring, print, assembly,
    flashing, software setup, first-run, troubleshooting
    - hardware/case: parametric OpenSCAD enclosure + base/lid/fit-test STLs + preview
    - LICENSE (MIT); README points to the build guide and case
    - firmware: pin presets cwd at this repo, SPI back to 27MHz, drop debug log
    [base.stl, claude-code-remote-case.scad, fit-test.stl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]
2026-06-07 Add boot session picker + fix headless auth
    - relay: support multiple runners per token as selectable sessions; route
    a device to the runner it picks; broadcast the session list
    - runner: announce a session name (SESSION_NAME / folder); send presets on
    device-attached; ignore an OAuth token mis-set as ANTHROPIC_API_KEY
    - firmware: ST_SESSIONS boot picker, select to control, BACK returns to it
    [main.cpp]
2026-06-07 Add screen sleep (backlight off after idle)
    Backlight moves to GPIO32 so firmware can switch it off after 60s idle and
    wake on any button (press consumed) or an incoming approval. ESP32 stays
    connected so live prompts are never missed. Docs/wiring updated (BLK->GPIO32).
    [main.cpp]
2026-06-13 Real-session list + read-only monitor + custom printed case
    - runner/relay: each runner reports its sessions (a live one + recent
    resumable Claude Code sessions from ~/.claude); relay merges across runners
    - read-only monitor: selecting a real session tails its transcript and
    streams the live conversation to a MONITOR screen on the device
    - firmware: ST_MONITOR screen; BACK returns to the picker
    - hardware/case: custom enclosure sized to the bolted ESP32+ST stack —
    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
    [base.stl, claude-code-remote-case.scad, fit-test.stl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]
